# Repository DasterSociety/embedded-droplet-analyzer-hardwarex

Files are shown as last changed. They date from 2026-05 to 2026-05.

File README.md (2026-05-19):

# Modular On-Chip Droplet Sensor System

Open-source hardware companion to a manuscript submitted to _HardwareX_.
The project describes a modular, on-chip sensor system for flow and
monodispersity analysis in droplet-based microfluidics.

> Zenodo DOI: _to be added once the first release is archived._
>
> Manuscript citation: _to be added after acceptance._

## Repository contents

| Folder | Contents | License |
| --- | --- | --- |
| [`design/hardware/`](design/hardware/) | PCB design files (Gerbers, drill files) for each sensor board.  | CERN-OHL-S v2 |
| [`design/mechanical/`](design/mechanical/) | 3D design exports (STEP, STL) for chip, housing, and sensor bodies. | CERN-OHL-S v2 |
| [`firmware/`](firmware/) | Microcontroller firmware and data-acquisition code. | CERN-OHL-S v2 |

## Licensing

All design files and firmware in this repository are licensed under the
[CERN Open Hardware Licence Version 2 — Strongly Reciprocal
(CERN-OHL-S v2)](LICENSE-hardware).

Each source file carries an SPDX identifier:

```
SPDX-License-Identifier: CERN-OHL-S-2.0
```

## How to cite

_Citation block to be added once the Zenodo DOI has been minted and the
HardwareX article has been assigned a DOI._

## Reproducing the hardware

Full build and operation instructions are in the companion *HardwareX* manuscript,
sections 5 (Build instructions) and 6 (Operation instructions). The Design files
summary (§3) and Bill of materials (§4) in the manuscript cross-reference the exact
files in this repository.

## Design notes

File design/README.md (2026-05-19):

# design

All design files for the hardware. Licensed under CERN-OHL-S v2.

| Folder | Contents |
| --- | --- |
| [`hardware/`](hardware/) | PCB design files (Gerbers, drill files) for each sensor board. |
| [`mechanical/`](mechanical/) | 3D design exports (STEP, STL) for chip, housing, and sensor bodies. |

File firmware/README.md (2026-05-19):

# Firmware

Microcontroller firmware and data-acquisition code that runs on the
sensor hardware. Include build instructions (toolchain, flashing steps)
in this folder once populated. Licensed under CERN-OHL-S v2.

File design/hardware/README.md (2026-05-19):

# hardware

PCB design files for the sensor electronics. Licensed under CERN-OHL-S v2.

Each subdirectory corresponds to one board and contains:

- `GerberFiles/` — Gerber layers (copper, silkscreen, soldermask, solderpaste, profile) and a `.gbrjob` job file.
- `DrillFiles/` — drill file (`.xln`).

## Boards

| Folder | Description |
| --- | --- |
| [`arduino_shield/`](arduino_shield/) | Arduino shield that interfaces the sensor boards with the microcontroller. |
| [`leds_board/`](leds_board/) | LED driver board for optical excitation. |
| [`velocity_sensor/`](velocity_sensor/) | PCB for the droplet velocity sensor. |

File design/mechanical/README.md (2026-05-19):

# mechanical

3D design exports for all physical parts of the system. Licensed under CERN-OHL-S v2.

Each subdirectory contains a `.step` (neutral CAD exchange) and a `.stl` (3D-printing / visualization) export for the corresponding part.

## Parts

| Folder | Description |
| --- | --- |
| [`arduino_shield/`](arduino_shield/) | Mechanical body / footprint model of the Arduino shield PCB. |
| [`bottom_enclosure/`](bottom_enclosure/) | Bottom half of the device enclosure. |
| [`leds_board/`](leds_board/) | Mechanical body / footprint model of the LED driver PCB. |
| [`microfluidic_device/`](microfluidic_device/) | Microfluidic chip body. |
| [`top_enclosure/`](top_enclosure/) | Top half of the device enclosure. |
| [`tsl2561_sensor/`](tsl2561_sensor/) | Housing / mounting bracket for the TSL2561 light-to-digital sensor. |
| [`velocity_sensor/`](velocity_sensor/) | Mechanical body / footprint model of the velocity sensor PCB. |

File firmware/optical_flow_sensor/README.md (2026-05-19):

# Optical Flow Sensor — Firmware

Open-source unified firmware for an Arduino Zero–based optical flow sensor that combines two functions in a single image:

1. **Capture mode** — phased-burst TSL2561 light-intensity logger; writes `LOG_NNN.CSV` files to a microSD card with deterministic 17 ms sample spacing.
2. **Analysis mode** — on-device droplet characterization; walks every `LOG_*.CSV` on the card, runs the detrend / zero-crossing / pairing pipeline, and reports a cumulative droplet-length summary (count, mean, std, CV%) over Serial.

Companion firmware to the *HardwareX* manuscript "[manuscript title TBD]". For day-to-day operation, see [`OPERATION.md`](./OPERATION.md).

## Status

Active development. Target hardware: **Arduino Zero** (Atmel SAMD21G18A, Cortex-M0+, 32 KB SRAM, 256 KB Flash).

This firmware supersedes the standalone [`TSL2561_logger`](../TSL2561_logger/) and [`droplet_characterization`](../droplet_characterization/) projects, which remain in the repository as reference implementations of the individual modes.

## Quick start

Requires [PlatformIO](https://platformio.org/).

```sh
cd firmware/optical_flow_sensor
pio run                # build
pio run -t upload      # build + flash to Arduino Zero
pio device monitor     # open Serial debug at 115200 baud
```

PlatformIO automatically pulls all library dependencies declared in `platformio.ini`.

## Modes at a glance

From STANDBY (green LED steady):

| Press | Mode | Outcome |
|---|---|---|
| **B1** | Capture | Records up to ~51 s into RAM, then offloads to `LOG_NNN.CSV`. Repeat as needed via the PROMPT loop; B2 ends the session and returns to STANDBY. |
| **B3** | Analysis | Walks every `LOG_*.CSV` in numerical order, prints one progress line per file, then a cumulative summary. Returns to STANDBY automatically. |

The TSL2561 sensor and the SD card are **both required at boot** — the firmware refuses to enter STANDBY otherwise (steady red = sensor missing; red fast-blink = SD missing).

## Architecture

**Single shared 24 KB buffer.** Capture and Analysis are mutually exclusive in time, so their two data layouts overlay the same physical SRAM via a `union` (`SharedBuffer::g_buf`):

- *Capture view* — `Sample[3000]` (uint32_t millis + float lux), 24 KB.
- *Analysis view* — parallel `uint16_t t[3000]` + `float L[3000]`, 18 KB.

This keeps RAM peak at ~25 KB (24 KB buffer + ~1.2 KB analysis index arrays + library state), well inside the SAMD21's 32 KB ceiling.

**Phased-burst capture.** Each Capture burst fills the RAM buffer with no SD activity, then offloads it to the next free `LOG_NNN.CSV`. Because the sensor and SD card never run concurrently, the timestamps within each file are uniform 17 000 µs apart with sub-millisecond jitter — any visible deviation is real sensor behaviour, not storage jitter.

**Single-shot per file analysis.** Each `LOG_NNN.CSV` is read end-to-end into the shared buffer, then processed in a single pass. Per-droplet lengths from each file are folded into a running Welford accumulator that lives across files, so the final cumulative summary is mathematically identical to merging every droplet length into one one-pass calculation. Welford's algorithm extends naturally across batches.

Pipeline (one call per file, plus a single summary at the end):

```
readCSV()        →  uint16_t t[]   (zeroed ms)  +  float L[]   (raw lux)
detrend()        →  L[] -= mean(L)              (in-place)
findCrossings()  →  all / falling / rising index arrays
findExtrema()    →  dominant peak/trough between consecutive crossings
checkSampling()  →  reports if any peak-to-trough gap is < 2 samples
pickCloserEdge() →  snap each crossing to the nearer-zero bracketing sample
pairDroplets()   →  match falling↔rising edges, drop incomplete leading/trailing
statsAdd()       →  fold this file's droplet lengths into the running Stats
                                       ┄
statsSummarize() →  final mean / std / CV%      (called once at end of pass)
```

## File layout

```
src/
├── Config.h              ← pin map, timing, buffer dimensions, Ud, LED-state table
├── Leds.{h,cpp}          ← LED helpers (allOff, green, red, yellow, blue)
├── Buttons.{h,cpp}       ← debounced active-low Button class
├── SensorTSL.{h,cpp}     ← TSL2561 wrapper (1× gain, 13 ms integration)
├── Sampler.{h,cpp}       ← fixed-grid scheduler, fills SharedBuffer in capture
├── Logger.{h,cpp}        ← SD lifecycle, OFS-compatible row writer
├── FileIterator.{h,cpp}  ← walks LOG_001.CSV … LOG_999.CSV on the SD card
├── DropletAnalysis.{h,cpp} ← detrend / crossings / pairing / Welford stats
├── SharedBuffer.{h,cpp}  ← 24 KB union shared between capture and analysis
└── main.cpp              ← unified state machine + setup() / loop()
```

## Output format

### Capture mode

Each `LOG_NNN.CSV` is a stream of rows with **no header**:

```
<millis_as_float_2dp>, <lux_2dp>\r\n
```

Example:

```
12345.00, 234.56
12362.00, 234.78
12379.00, 234.55
```

The format matches the *OFS* detection pipeline's expected input (`OFS/Software Dev/OFS/lib/MyLib/Library.cpp:TSLReading_a`), so existing analysis code can read these files unchanged. Timestamps are milliseconds since power-on, captured immediately before the TSL2561 read.

### Analysis mode

Serial output at 115 200 baud. One compact line per file as it is processed:

```
LOG_001.CSV : 17 droplets (3000 samples)
LOG_002.CSV : 16 droplets (3000 samples, 1 undersampled)
```

Then a single cumulative block:

```
=== Cumulative results ===
Files processed: 2
Total droplets : 33
Avg length     : 612.34 um
Std dev        : 11.20 um
CV             : 1.83 %
```

Files that fail to read are reported as `LOG_NNN.CSV : read failed` and counted under `Files failed:` in the cumulative block.

## Configuration

Compile-time knobs in `src/Config.h`:

| Constant | Default | Meaning |
|---|---|---|
| `UD_MM_PER_S` | 1.55089 | Droplet velocity along the optical sensing path; sets the µm scale of the reported lengths |
| `SAMPLE_PERIOD_US` | 17 000 | Inter-sample interval in capture (~58 Hz) |
| `BUFFER_SIZE_SAMPLES` | 3 000 | Per-burst capacity (24 KB → ~51 s) |
| `MAX_CROSSINGS` | 100 | Upper bound on rising+falling crossings per file |
| `DEBOUNCE_MS` | 50 | Button debounce window |
| `FLUSH_EVERY_N` | 100 | SD-flush cadence during offload (crash-resilience) |
| `OFFLOAD_BLINK_MS` | 100 | OFFLOADING yellow fast-blink half-period |
| `PROMPT_BLINK_MS` | 500 | PROMPT green slow-blink half-period |
| `ERROR_BLINK_MS` | 200 | ERROR_SD red fast-blink half-period |
| `REJECT_FLASH_MS` | 400 | Brief red flash for rejected button press (e.g. analysis with no LOG files) |
| `DEBUG_OFS` | 1 | Set to 0 to disable all Serial output |

`SAMPLE_PERIOD_US` cannot go below ~14 000 µs without changing the TSL2561 driver — the 13 ms integration window plus driver overhead is the hard floor. `BUFFER_SIZE_SAMPLES` can be raised toward ~4000 on a 32 KB SAMD21 before the stack and library state become tight.

Length is computed as `length_k = (t_rise - t_fall) [ms] × Ud [µm/ms = mm/s]`, so `Ud` is the only experiment-specific value that needs to be fixed before flashing.

## Dependencies

Declared in `platformio.ini`, pulled automatically:

- `arduino-libraries/SD ^1.2.4`
- `adafruit/Adafruit Unified Sensor ^1.1.13`
- `adafruit/Adafruit TSL2561 ^1.1.0`

## Hardware

A minimal build requires:

- Arduino Zero (or compatible SAMD21G18A board)
- Adafruit TSL2561 breakout (or equivalent) on I²C
- microSD card module on hardware SPI, chip-select on D4
- 4 LEDs (green, red, yellow, blue) with current-limiting resistors
- 3 push buttons (B1, B2, B3) wired to ground

Full bill of materials, schematic, and assembly are in the *HardwareX* manuscript.

## License

CERN Open Hardware Licence Version 2 — Strongly Reciprocal (CERN-OHL-S v2).
See [`LICENSE-hardware`](../../LICENSE-hardware) at the repository root.

## Citation

If you use this firmware, please cite:

> [manuscript citation TBD]

## Maintainer

[Author / maintainer block TBD — e.g., name, affiliation, contact.]

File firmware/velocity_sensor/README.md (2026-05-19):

# Velocity Sensor — Firmware

Arduino Zero firmware for the dual-comparator optical droplet velocity sensor.
Companion firmware to the *HardwareX* manuscript.

## What this firmware does

Measures droplet velocity in a microfluidic channel by timing the transit between
two optical comparator sensors (COMP_A and COMP_B) separated by a known distance.
A SCADE-generated state machine processes the interrupt events and outputs velocity
in mm/s over Serial at 38 400 baud.

## Hardware requirements

- Arduino Zero (Atmel SAMD21G18A, Cortex-M0+)
- Two optical comparator outputs connected to D7 (COMP_A) and D6 (COMP_B)
- Two digital potentiometers (I²C address `0x2F`) for threshold adjustment:
  - DigiPot 1 on the default I²C bus (SDA/SCL)
  - DigiPot 2 on a second I²C bus (SDA = D11, SCL = D13)
- Status LEDs: green (D8), red (D9), yellow (D12), blue (A5), velocity LED (D10), OFS LED (A4)
- Buttons: B1 (D2), B2 (D3), B3 (D5) — active-low with internal pull-ups

Full bill of materials, schematic, and assembly are in the *HardwareX* manuscript.

## Quick start

Requires [PlatformIO](https://platformio.org/).

```sh
cd firmware/velocity_sensor
pio run                # build
pio run -t upload      # build + flash to Arduino Zero
pio device monitor     # open Serial at 38400 baud
```

## Configuration

Compile-time constants in `src/main.cpp`:

| Constant | Default | Meaning |
|---|---|---|
| `WIPER1` | 76 | DigiPot 1 wiper — sets COMP_B (Sensor 2) threshold |
| `WIPER2` | 83 | DigiPot 2 wiper — sets COMP_A (Sensor 1) threshold |
| `n` | 2 | Number of sensors active in the SCADE state machine |
| `DEBOUNCE_TIME_US` | 1000 | ISR debounce window (µs) |
| `MIN_INTER_S1_US` | 3000 | Minimum inter-event gap for Sensor 1 (µs) |
| `MIN_INTER_S2_US` | 3000 | Minimum inter-event gap for Sensor 2 (µs) |

The wiper values control the comparator thresholds and must be tuned to the signal
amplitude from your specific optical sensor assembly.

## Serial output

At 38 400 baud, the firmware prints one velocity value per detected droplet:

```
>>> Optical Droplet Velocity Sensor [OFS 3.0] <<<
Digital Potentiometer 1: 76
Digital Potentiometer 2: 83
n: 2
=== Velocity Measurements with ISR Debug ===
...
12.34
13.01
12.89
```

Each floating-point number is a droplet velocity in mm/s. Only values that differ
from the previous measurement and are > 0 are printed.

## Dependencies

Declared in `platformio.ini`; no external libraries are required beyond the
Arduino framework (pulled automatically by PlatformIO).

The SCADE/KCG state-machine code in `lib/KCG/` is a local library bundled with
the project and generated from the model file `VelSensor.cgcs`.

## License

CERN Open Hardware Licence Version 2 — Strongly Reciprocal (CERN-OHL-S v2).
See [`LICENSE-hardware`](../../LICENSE-hardware) at the repository root.

## Citation

If you use this firmware, please cite:

> [manuscript citation TBD — to be added after HardwareX acceptance]

## Maintainer

[Author block TBD — to be added before publication]

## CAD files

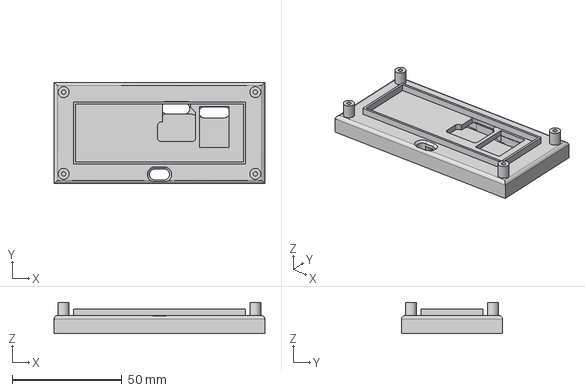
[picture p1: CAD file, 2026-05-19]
design/mechanical/bottom_enclosure/bottom_enclosure.step
96.0 x 46.0 x 14.3 mm

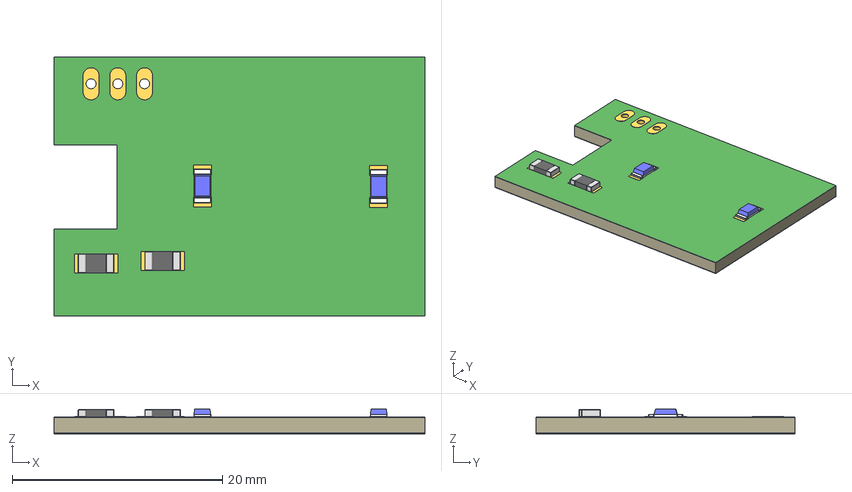
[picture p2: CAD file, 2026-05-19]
design/mechanical/leds_board/leds_board.step
35.3 x 24.6 x 2.37 mm
Board
1-copper
16-copper
1-soldermask
16-soldermask
RESC3216X70 x 2

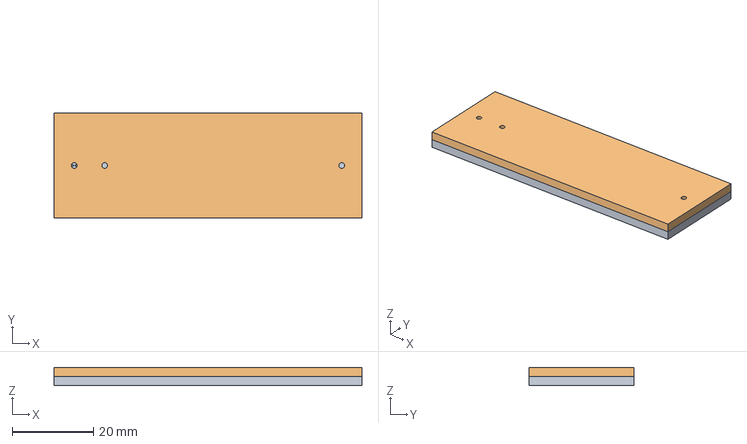
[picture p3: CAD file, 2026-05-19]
design/mechanical/microfluidic_device/microfluidic_device.step
76.0 x 26.0 x 4.46 mm

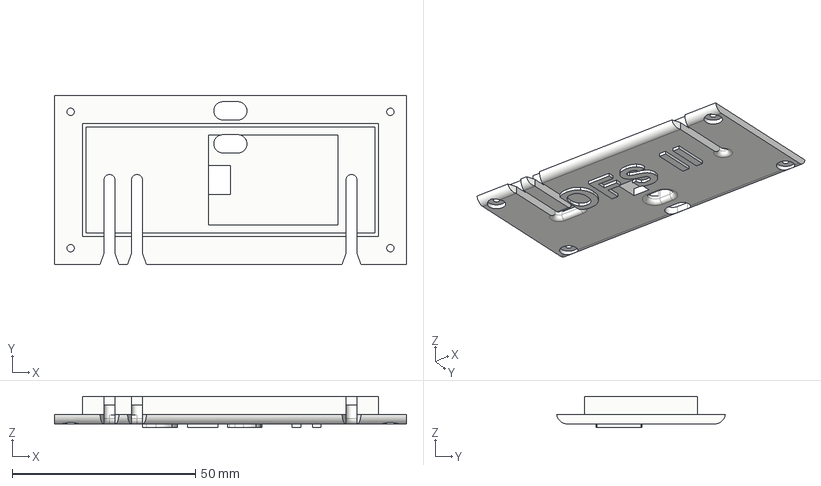
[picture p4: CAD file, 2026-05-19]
design/mechanical/top_enclosure/top_enclosure.step
96.0 x 46.0 x 8.50 mm

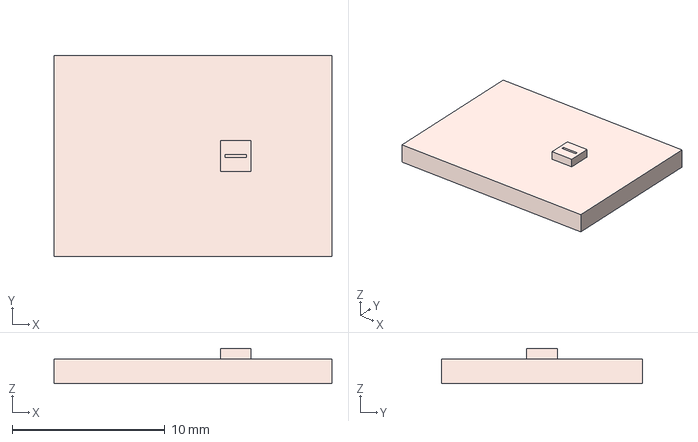
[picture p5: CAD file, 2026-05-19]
design/mechanical/tsl2561_sensor/tsl2561_sensor.step
18.2 x 13.2 x 2.30 mm

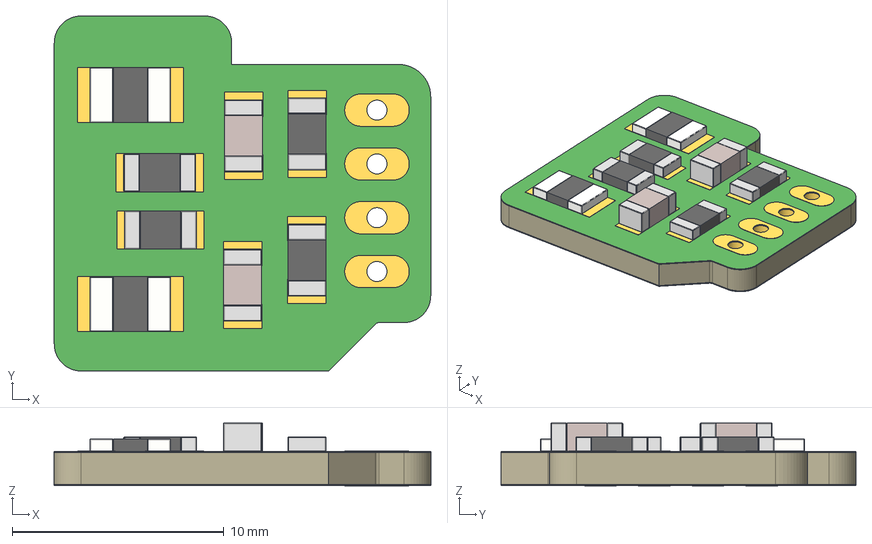
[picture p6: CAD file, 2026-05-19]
design/mechanical/velocity_sensor/velocity_sensor.step
17.8 x 16.8 x 2.97 mm
Board
1-copper
16-copper
1-soldermask
16-soldermask
12912179.f3d x 4
CAPC3216X135 x 2

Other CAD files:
design/mechanical/bottom_enclosure/bottom_enclosure.stl
design/mechanical/leds_board/leds_board.stl
design/mechanical/microfluidic_device/microfluidic_device.stl
design/mechanical/top_enclosure/top_enclosure.stl
design/mechanical/tsl2561_sensor/tsl2561_sensor.stl
design/mechanical/velocity_sensor/velocity_sensor.stl

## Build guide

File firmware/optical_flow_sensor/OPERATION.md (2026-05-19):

# Operation Manual

This manual covers day-to-day use of the optical flow sensor in both modes: capturing recordings and analysing them on-device. For build instructions and architectural details, see [`README.md`](./README.md). For the bill of materials and assembly, see the *HardwareX* manuscript.

## What this device does

A single press from STANDBY chooses one of two modes:

- **Capture mode (B1)** — samples ambient light intensity from the TSL2561 at ~58 Hz and stores each recording session as a self-contained CSV file on the microSD card. A single burst captures up to ~51 s of data into RAM with deterministic timing, then writes it out to the next available `LOG_NNN.CSV` file. Multiple bursts can be captured back-to-back.
- **Analysis mode (B3)** — walks every existing `LOG_*.CSV` on the card in numerical order, runs the droplet characterization pipeline on each file, and prints a cumulative summary (file count, droplet count, mean length, standard deviation, CV%) over Serial. Returns to STANDBY automatically when done.

## Hardware overview

Pin assignments are fixed in firmware (`src/Config.h`) and must match how your board is wired:

| Function | Pin | Notes |
|---|---|---|
| Capture button (B1) | D2 | Active-low, INPUT_PULLUP |
| End-session button (B2) | D3 | Active-low, INPUT_PULLUP |
| Analysis button (B3) | D5 | Active-low, INPUT_PULLUP |
| Green LED | D8 | Standby / capturing |
| Red LED | D9 | Error / rejected press |
| Yellow LED | D12 | Init / offloading / prompt / processing |
| Blue LED | A5 | Capturing / processing |
| SD chip-select | D4 | |
| TSL2561 SDA / SCL | board defaults | I²C |
| SD MOSI / MISO / SCK | board defaults | hardware SPI (fixed on Zero) |

## Preparing the SD card

1. Format the card as **FAT32**.
   - macOS: Disk Utility → Erase → MS-DOS (FAT).
   - Windows: SD Memory Card Formatter (recommended for cards larger than 32 GB).
2. Confirm the card mounts cleanly. Existing `LOG_NNN.CSV` files from previous sessions are fine — the firmware skips occupied filenames during Capture and walks every existing one during Analysis.
3. Insert the card into the SD module **before powering the device**.

The firmware refuses to leave INIT (red fast-blink) if no card is detected.

## LED reference

| LED state | Meaning |
|---|---|
| Yellow steady | Initialising — testing TSL2561 and SD card |
| Green steady | **Standby** — ready (B1 = Capture, B3 = Analysis) |
| Green steady + Blue steady | **Capturing** — RAM buffer filling, do not remove power |
| Yellow fast-blink (~10 Hz) | **Offloading** — writing buffer to SD, do not remove power or card |
| Yellow steady + Green slow-blink (~1 Hz) | **Prompt** — choose: B1 for next file, B2 to end session |
| Yellow steady + Blue steady | **Processing** — analysing LOG files |
| Brief red flash (~400 ms) | Pressed button valid for some mode but unavailable now (e.g. B3 with no LOG files on card) |
| Red steady | TSL2561 not detected at boot |
| Red fast-blink (~5 Hz) | SD card error |

## Button reference

| Button | Active state | Action |
|---|---|---|
| B1 | Standby | Enter Capture mode (start a recording burst) |
| B1 | Capturing | Stop the current burst early and offload |
| B1 | Prompt | Start the next burst (new file) |
| B2 | Prompt | End the session and return to Standby |
| B3 | Standby | Enter Analysis mode (process every `LOG_*.CSV`) |

Button presses outside the active states listed above are ignored.

## Recording an experiment — step by step

### 1. Power on

Connect the device via USB or its dedicated power input. Watch the LEDs:

- The yellow LED comes on briefly (initialisation, < 1 s).
- The green LED comes on steadily — you are now in **Standby**.

If a red LED comes on instead, see *Troubleshooting* below before proceeding.

### 2. Start a recording

Press **B1**. The blue LED comes on (the green LED stays on). The device is now capturing data into RAM at ~58 Hz. Avoid pressing other buttons during capture unless you want to stop early.

### 3. Wait, or stop early

Capture continues until either of:

- You press **B1** again (manual stop), or
- The 51-second buffer fills (automatic stop).

In either case, capture ends and offload begins automatically.

### 4. Wait for the offload

The blue and green LEDs go off; the yellow LED begins fast-blinking. The firmware is writing the captured data to the next free `LOG_NNN.CSV` file on the SD card. **Do not remove power or the SD card during this phase.** Offload typically takes 1–3 s on a healthy card.

### 5. Decide what to do next

When offload finishes you enter **Prompt**: yellow LED steady, green LED slow-blinking.

- **Press B1** to start another recording immediately. The next file is auto-numbered (e.g., `LOG_002.CSV` after `LOG_001.CSV`).
- **Press B2** to end the session. The device returns to Standby (green LED steady), at which point it is safe to remove the SD card or power-cycle.

### 6. Repeat as needed

A single session can capture as many files as the SD card has space for, up to file 999. There is no hard limit on the number of sessions per card other than the 999 file-slot ceiling.

## Running an analysis pass — step by step

### 1. From STANDBY, press B3

The green LED switches off; yellow + blue come on (Processing). The firmware walks every `LOG_*.CSV` on the card in numerical order, fold-merging the per-droplet lengths from each file into a single Welford accumulator.

If the card has no `LOG_*.CSV` files, the red LED briefly flashes (~400 ms) and the device stays in Standby — there is nothing to analyse.

### 2. Watch the Serial monitor

At 115 200 baud you'll see one compact line per file as it completes:

```
LOG_001.CSV : 17 droplets (3000 samples)
LOG_002.CSV : 16 droplets (3000 samples, 1 undersampled)
```

The `undersampled` annotation means at least one peak-to-trough transition was resolved by fewer than 2 samples in that file — flag for manual review but the droplet count is still computed.

### 3. Read the cumulative summary

After the last file, the firmware prints:

```
=== Cumulative results ===
Files processed: 2
Total droplets : 33
Avg length     : 612.34 um
Std dev        : 11.20 um
CV             : 1.83 %
```

The yellow + blue LEDs go off and the green LED returns to steady — back in **Standby**, ready for either mode again. The analysis pass does not modify the SD card.

### 4. Re-run if needed

Pressing **B3** again re-runs the same pass with a fresh Welford accumulator (the previous summary remains in the Serial scrollback). Useful after editing/replacing files on the card.

## State diagram

```
                 ┌─────┐
                 │INIT │ Y on
                 └──┬──┘
                    │ TSL2561 + SD OK
                    ▼
       ┌───────► STANDBY  ◄──────────────────────────┐
       │         G on                                │
       │       ┌──┴──┐                               │
       │      B1     B3                              │
       │       │      │                              │
       │       ▼      ▼                              │
       │   CAPTURING  PROCESSING                     │
       │   G + B on   Y + B on                       │
       │       │      │                              │
       │   B1 / full  walks LOG_*.CSV                │
       │       ▼      │ prints cumulative summary    │
       │   OFFLOADING └──────────────────────────────┘
       │   Y fast-blink
       │       │
       │       ▼
       │     PROMPT  Y on, G slow-blink
       │     ├── B1 → CAPTURING (next file)
       │     └── B2 → STANDBY
       └───────────
```

## Recovering data from the card

1. End the capture session: in Prompt state, press **B2** so the green LED goes steady.
2. Remove power.
3. Eject the microSD card and read it on a computer.
4. Copy the `LOG_NNN.CSV` files to your analysis directory.

Each file is plain CSV, no header, format `<millis_as_float>, <lux>` per row:

```
12345.00, 234.56
12362.00, 234.78
12379.00, 234.55
```

Timestamps are milliseconds since the Arduino was powered on (boot-relative). Within a single file, samples are uniformly spaced 17 ms apart with sub-millisecond jitter; the act of writing to SD did **not** influence the spacing because no SD activity occurred during capture.

## Specifications

| Parameter | Value |
|---|---|
| Sample rate | ~58 Hz (one sample every 17 ms) |
| TSL2561 gain | 1× |
| TSL2561 integration time | 13 ms (fastest setting) |
| Maximum file duration | ~51 s (3000 samples × 17 ms) |
| Maximum files per card | 999 (`LOG_001` … `LOG_999`) |
| File format | CSV, no header, OFS-compatible |
| Timestamp resolution | 1 ms (since power-on) |
| Timestamp format | float, 2 decimal places |
| Lux format | float, 2 decimal places |
| Per-burst SRAM use | 24 KB (shared with analysis buffer) |
| Analysis pass time | < 1 s per LOG file on a healthy card |

## Troubleshooting

**Red LED steady at boot.**
The TSL2561 is not responding on I²C. Check SDA/SCL wiring, sensor power, and confirm the address strap (default `TSL2561_ADDR_FLOAT`) matches your breakout board. Power-cycle to retry.

**Red LED fast-blink at boot.**
SD card not detected or unreadable. Confirm the card is inserted, formatted as FAT32, and that chip-select (D4) is wired correctly. Power-cycle to retry.

**Red LED fast-blink during operation.**
Could not open a new `LOG_NNN.CSV` file during offload. Either all 999 slots are taken, or the card is full. Move some old files off the card (or use a fresh card) and power-cycle.

**Brief red flash when pressing B3.**
There are no `LOG_*.CSV` files on the card to analyse. Run a Capture pass first, or insert a card that already has logs.

**Offload phase takes much longer than expected.**
Consumer SD cards occasionally pause for several seconds to perform internal garbage collection. The yellow LED continues fast-blinking throughout — this is normal. If a card consistently exceeds 10 s for a 24 KB write, replace it with a known-good card.

**File appears truncated after a power loss.**
Mid-offload power loss leaves a partial file containing every row written before the last `flush()` (every 100 rows by default). The remainder of the buffer is lost. To minimise risk, ensure the device is powered until the yellow LED returns to steady before disconnecting.

**Analysis prints `LOG_NNN.CSV : read failed`.**
The file could not be opened (corrupt entry, encrypted card, or transient SD glitch). The pass continues with subsequent files; the failed file is counted under `Files failed:` in the cumulative summary.

**Some files report `undersampled`.**
At least one peak-to-trough transition in that file was resolved by fewer than 2 samples — typically a sign that flow rate or droplet frequency was high relative to the 58 Hz sample rate. The droplet count is still computed but the per-file length estimates may be biased; treat the affected file as a soft warning.

**The Serial monitor shows nothing.**
Confirm the monitor is at 115 200 baud. Note that `DEBUG_OFS` is enabled by default; set it to `0` in `src/Config.h` for a silent release build.

**Buffer fills sooner than ~51 s in Capture.**
Confirm `BUFFER_SIZE_SAMPLES` and `SAMPLE_PERIOD_US` in `src/Config.h` have not been altered. At defaults (3000 samples × 17 000 µs), the burst lasts 51.0 s.

## Recompiling the firmware

See [`README.md`](./README.md) for the build process. The compile-time constants in `src/Config.h` can be tuned without touching any other file:

- Edit **`UD_MM_PER_S`** to match your experiment's droplet velocity (mm/s). This is the only value that has to change between experiments; lengths reported in Analysis mode scale linearly with it.
- Increase **`BUFFER_SIZE_SAMPLES`** to extend per-file duration. Up to ~4000 is safe on the 32 KB SAMD21; beyond that the stack and library state become tight.
- Decrease **`SAMPLE_PERIOD_US`** to push the sample rate. Below ~14 000 µs the TSL2561 driver cannot keep up — the 13 ms integration window is a hard floor.
- Set **`DEBUG_OFS = 0`** for a release build with no Serial output.

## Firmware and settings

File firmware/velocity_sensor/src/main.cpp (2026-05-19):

#include <Arduino.h>
#include <Wire.h>
#include "wiring_private.h"
#include "velSensor.h"
#include "velSensor.c"
// Clean version Win

// NOTE: Second I2C port: SDA 11; SCL 13;
//  Seting second I2C port to use pins 11 and 13
#define digiPot 0x2F // I2C address of the digital potentiometers
TwoWire myWire(&sercom1, 11, 13);

// NOTE: I/O pins of new Arduino Shield:
const uint8_t LED_R = 9;
const uint8_t LED_G = 8;
const uint8_t LED_Y = 12;
const uint8_t LED_B = A5;
const uint8_t LED_VEL = 10; // Light source for Vel Sensor
const uint8_t LED_OFS = A4; // Light source for OFS TSL2561
const uint8_t button1 = 2;  // Button 1
const uint8_t button2 = 3;  // Button 2
const uint8_t button3 = 5;  // Button 3

// NOTE: Velocity Sensor Comparator output pins:

const uint8_t comp_s1 = 7; // COMP_A
const uint8_t comp_s2 = 6; // COMP_B

// Globals
volatile unsigned long lastTriggerTime_s1 = 0; // Last trigger time for Sensor 1
volatile unsigned long lastTriggerTime_s2 = 0; // Last trigger time for Sensor 2
volatile unsigned long lastValidS1Time = 0;    // Timestamp of last accepted ISR1
volatile unsigned long lastValidS2Time = 0;    // Timestamp of last accepted ISR2

// Debounce timing constants
const unsigned long DEBOUNCE_TIME_US = 1000; // 1ms debounce for high-speed droplets
const unsigned long MIN_INTER_S1_US = 3000;   // Ignore S1 edges <3ms after previous valid S1
const unsigned long MIN_INTER_S2_US = 3000;   // Ignore S2 edges <3ms after previous valid S2

// NOTE: Digipots Wiper values:
// CONFIG: W1 -> DigiPot1 -> COMP_1 -> Sensor 2 (Second sensor contacted to the droplet)
// CONFIG: W2 -> DigiPot2 -> COMP_2 -> Sensor 1 (First sensor contacted to the droplet)
// CONFIG: n -> Number of droplets to reset timer 2.

const uint8_t WIPER1 = 76; // RED
const uint8_t WIPER2 = 83; // GREEN
const uint8_t n = 2;       // Number of sensors (1 or 2)

// NOTE: SCADE init variables
inC_velSensor inC;
outC_velSensor outC;
kcg_uint32 Time = 0;
kcg_bool fs1 = false;
kcg_bool fs2 = false;
float prevVel;

void isr_1()
{
  // Interrupt for COMP_A (Sensor 1 - First sensor contacted by droplet)
  unsigned long currentTime = micros();
  unsigned long elapsedTime = currentTime - lastTriggerTime_s1;

  // Improved debouncing and per-sensor inter-event guard
  if (elapsedTime > DEBOUNCE_TIME_US && (currentTime - lastValidS1Time) > MIN_INTER_S1_US && digitalRead(comp_s1) == HIGH)
  {
    lastTriggerTime_s1 = currentTime;
    lastValidS1Time = currentTime;
    fs1 = true;     // Set SCADE input flag

    // Lightweight ISR: capture timestamp and signal main loop to process SCADE
    Time = currentTime;     // Capture timestamp associated with this event
  }
}

void isr_2()
{
  // Interrupt for COMP_B (Sensor 2 - Second sensor contacted by droplet)
  unsigned long currentTime = micros();
  unsigned long elapsedTime = currentTime - lastTriggerTime_s2;

  // Improved debouncing and per-sensor inter-event guard
  if (elapsedTime > DEBOUNCE_TIME_US && (currentTime - lastValidS2Time) > MIN_INTER_S2_US && digitalRead(comp_s2) == HIGH)
  {
    lastTriggerTime_s2 = currentTime;
    lastValidS2Time = currentTime;
    fs2 = true;     // Set SCADE input flag

    // Lightweight ISR: capture timestamp and signal main loop to process SCADE
    Time = currentTime;     // Capture timestamp associated with this event
  }
}

void setWiper(TwoWire &bus, uint8_t value)
{
  // Set the wiper value for the digital potentiometer
  bus.beginTransmission(digiPot);
  bus.write(value); // Set the wiper value
  bus.endTransmission();
}

void setupPins()
{
  // Set pin modes for all I/O pins
  pinMode(comp_s1, INPUT);        // Comparator output for Sensor 1
  pinMode(comp_s2, INPUT);        // Comparator output for Sensor 2
  pinMode(LED_VEL, OUTPUT);       // Velocity sensor LED
  pinMode(LED_B, OUTPUT);         // Blue LED indicator
  pinMode(LED_Y, OUTPUT);         // Yellow LED indicator
  pinMode(LED_R, OUTPUT);         // Red LED indicator
  pinMode(LED_G, OUTPUT);         // Green LED indicator
  pinMode(LED_OFS, OUTPUT);       // OFS TSL2561 LED
  pinMode(button1, INPUT_PULLUP); // Button 1 with pullup
  pinMode(button2, INPUT_PULLUP); // Button 2 with pullup
  pinMode(button3, INPUT_PULLUP); // Button 3 with pullup

  // Initialize LED states
  digitalWrite(LED_VEL, HIGH); // Turn on velocity sensor LED
  digitalWrite(LED_B, LOW);    // Turn off other LEDs initially
  digitalWrite(LED_Y, LOW);
  digitalWrite(LED_R, LOW);
  digitalWrite(LED_G, LOW);
  digitalWrite(LED_OFS, LOW);
}

void setup()
{
  // SCADE function initialization
  velSensor_init(&outC); // Initialize SCADE function
  // Initialize I2C
  Wire.begin();                  // Initialize I2C
  myWire.begin();                // Initialize second I2C port
  pinPeripheral(11, PIO_SERCOM); // Set pin 11 to SERCOM mode
  pinPeripheral(13, PIO_SERCOM); // Set pin 13 to SERCOM mode

  // Initialize serial communication
  Serial.begin(38400);
  Serial.println(">>> Optical Droplet Velocity Sensor [OFS 3.0] <<<");
  delay(10);

  // Set digiPot wiper values
  setWiper(Wire, WIPER1);   // Set wiper value for DigiPot1
  setWiper(myWire, WIPER2); // Set wiper value for DigiPot2
  myWire.end();
  Wire.end();

  // Set up all pin modes and initial states
  setupPins();

  // Set up interrupts
  attachInterrupt(digitalPinToInterrupt(comp_s1), isr_1, RISING); // Attach interrupt for COMP_A
  attachInterrupt(digitalPinToInterrupt(comp_s2), isr_2, RISING); // Attach interrupt for COMP_B

  inC.n = n; // Set input count for Sensor 2

  // Print initial message
  Serial.print("Digital Potentiometer 1: ");
  Serial.println(WIPER1);
  Serial.print("Digital Potentiometer 2: ");
  Serial.println(WIPER2);
  Serial.print("n: ");
  Serial.println(inC.n);
  Serial.println("=== Velocity Measurements with ISR Debug ===");
  Serial.println("Format: Vel: [velocity] mm/s, ISR1 calls: [count], ISR2 calls: [count], n: [counter], startTime: [us], stopTime: [us], timeDiff: [us]");
  Serial.println("DEBUG format: TimerInit, TimerStop, Counter_s2, ISR1 total, ISR2 total, fs1, fs2");
  Serial.println("ISR Debug: ISR1/ISR2 with count, Time, timer states, and timing values");
  delay(1000);
}

void loop()
{
  // Update LED indicators based on SCADE outputs
  digitalWrite(LED_B, outC.timerInit);
  digitalWrite(LED_Y, outC.timerStop);

  // Process SCADE in main loop when flags are set (no debug prints)
  if (fs1 || fs2)
  {
    velSensor(&inC, &outC);
  }

  // Print velocity only if it changed and is valid
  if (outC.vel != prevVel && outC.vel > 0.0)
  {
    Serial.println(outC.vel);
    prevVel = outC.vel;
  }

  // No periodic debug to keep serial line quiet

  // Reset sensor flags in main loop (safer than in ISR)
  // This prevents potential race conditions
  if (fs1 == true)
  {
    fs1 = false;     // Reset SCADE flag for Sensor 1
  }
  if (fs2 == true)
  {
    fs2 = false;     // Reset SCADE flag for Sensor 2
  }
}

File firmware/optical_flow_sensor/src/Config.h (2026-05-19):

#pragma once

#include <Arduino.h>

#ifndef DEBUG_OFS
#define DEBUG_OFS 1
#endif

namespace Config {

// ── Timing ────────────────────────────────────────────────────────────────────
constexpr unsigned long DEBOUNCE_MS         = 50;
constexpr unsigned long SAMPLE_PERIOD_US    = 17000;   // ~58 Hz: 13 ms TSL2561 integration + overhead
constexpr unsigned long ERROR_BLINK_MS      = 200;     // SD error: red LED half-period
constexpr unsigned long OFFLOAD_BLINK_MS    = 100;     // OFFLOADING: yellow fast-blink half-period
constexpr unsigned long PROMPT_BLINK_MS     = 500;     // PROMPT: green slow-blink half-period
constexpr unsigned long REJECT_FLASH_MS     = 400;     // brief red flash for rejected button press
constexpr unsigned long SERIAL_WAIT_MS      = 3000;    // 0 = don't wait for USB serial
constexpr unsigned int  FLUSH_EVERY_N       = 100;     // crash-resilience during offload

// ── Buffer dimensions ─────────────────────────────────────────────────────────
// 3000 samples × 17 ms ≈ 51 s per LOG_NNN.CSV file.
// Capture view (Sampler::Sample[]):  3000 × 8 B = 24 KB
// Analysis view (uint16_t t[] + float L[]): 3000 × 6 B = 18 KB
// Both views overlay the same physical buffer (SharedBuffer::g_buf) — modes are
// mutually exclusive in time, so the union is safe.
constexpr size_t   BUFFER_SIZE_SAMPLES = 3000;
constexpr uint16_t MAX_CROSSINGS       = 100;

// ── Experiment parameter ──────────────────────────────────────────────────────
// Droplet velocity along the optical sensing path.
// length_k [µm] = (t_rise - t_fall) [ms] × Ud [µm/ms = mm/s]
// Edit and rebuild to match your experiment.
constexpr float UD_MM_PER_S = 1.55089f;

// ── Pins ──────────────────────────────────────────────────────────────────────
constexpr uint8_t PIN_B1    = 2;    // STANDBY: enter Capture; CAPTURING: stop early; PROMPT: next burst
constexpr uint8_t PIN_B2    = 3;    // PROMPT: end session → STANDBY
constexpr uint8_t PIN_B3    = 5;    // STANDBY: enter Analysis
constexpr uint8_t PIN_LED_G = 8;    // ready / capturing
constexpr uint8_t PIN_LED_R = 9;    // error / rejected press
constexpr uint8_t PIN_LED_Y = 12;   // init / offloading / prompt / processing
constexpr uint8_t PIN_LED_B = A5;   // capturing / processing
constexpr uint8_t PIN_SD_CS = 4;

// ── LED state table (informational; states drive these in main.cpp) ───────────
//   INIT        → Y on
//   STANDBY     → G on
//   CAPTURING   → G on  + B on
//   OFFLOADING  → Y fast-blink
//   PROMPT      → Y on  + G slow-blink
//   PROCESSING  → Y on  + B on
//   ERROR_TSL   → R steady
//   ERROR_SD    → R fast-blink

}  // namespace Config

#if DEBUG_OFS
  #define DBG(x)   Serial.print(x)
  #define DBGLN(x) Serial.println(x)
#else
  #define DBG(x)
  #define DBGLN(x)
#endif

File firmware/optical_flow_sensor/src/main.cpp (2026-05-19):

/*
 * Optical Flow Sensor — unified firmware (capture + analysis)
 * Board : Arduino Zero (SAMD21 Cortex-M0+)
 *
 * Two user-selectable modes from STANDBY:
 *   B1 → Capture mode    : phased-burst light intensity logger that writes
 *                          LOG_NNN.CSV files to the microSD card. Mirrors the
 *                          standalone TSL2561 logger flow.
 *   B3 → Analysis mode   : walks every LOG_*.CSV on the card, runs the droplet
 *                          characterization pipeline, prints per-file progress
 *                          and a cumulative summary, then returns to STANDBY.
 *
 * Capture and analysis are mutually exclusive in time, so the 24 KB sample
 * buffer is shared between them via SharedBuffer::g_buf.
 *
 * Pin map
 * -------
 *   D2   B1   STANDBY: enter Capture; CAPTURING: stop early; PROMPT: next burst
 *   D3   B2   PROMPT: end session → STANDBY
 *   D5   B3   STANDBY: enter Analysis
 *   D8   LED_G  ready / capturing / prompt slow-blink
 *   D9   LED_R  error / rejected press
 *   D12  LED_Y  init / offloading / prompt / processing
 *   A5   LED_B  capturing / processing
 *   D4   SD chip-select
 *   SDA/SCL    TSL2561 I2C
 *   MOSI=23, MISO=22, SCK=24  (hardware SPI, fixed on Zero)
 *
 * State machine
 * -------------
 *   INIT       (Y on)            — probe TSL2561 + SD; both required
 *   STANDBY    (G on)            — B1 → CAPTURING, B3 → PROCESSING
 *   CAPTURING  (G + B on)        — RAM buffer fills; B1 or buffer-full → OFFLOADING
 *   OFFLOADING (Y fast-blink)    — buffer is written to LOG_NNN.CSV; auto → PROMPT
 *   PROMPT     (Y on, G slow-blink)
 *                                — B1 → CAPTURING (next file); B2 → STANDBY
 *   PROCESSING (Y + B on)        — walk LOG_*.CSV, fold into Welford, print summary; auto → STANDBY
 *   ERROR_TSL  (R steady)        — TSL2561 not found at boot
 *   ERROR_SD   (R fast-blink)    — SD mount failed
 *
 * CSV format (per row)
 * --------------------
 *   "<millis_as_float_2dp>, <lux_2dp>\r\n"   — no header.
 *   Matches the OFS project's Serial output (Library.cpp:TSLReading_a) so the
 *   existing detection pipeline can read these files unchanged.
 *
 * Compile-time experiment parameter
 * ---------------------------------
 *   Config::UD_MM_PER_S — droplet velocity along the sensing path.
 *   Edit Config.h and rebuild to match your experiment.
 */

#include <Arduino.h>

#include "Config.h"
#include "Leds.h"
#include "Buttons.h"
#include "SensorTSL.h"
#include "Sampler.h"
#include "Logger.h"
#include "FileIterator.h"
#include "DropletAnalysis.h"
#include "SharedBuffer.h"

// ── Static SRAM (analysis-only working arrays, ~1.2 KB) ───────────────────────
static uint16_t g_allCrossings[Config::MAX_CROSSINGS];
static uint16_t g_fallingIdx[Config::MAX_CROSSINGS];
static uint16_t g_risingIdx[Config::MAX_CROSSINGS];
static uint16_t g_extremaIdx[Config::MAX_CROSSINGS];
static uint16_t g_fallingPts[Config::MAX_CROSSINGS];
static uint16_t g_risingPts[Config::MAX_CROSSINGS];

enum class State : uint8_t
{
    INIT,
    STANDBY,
    CAPTURING,
    OFFLOADING,
    PROMPT,
    PROCESSING,
    ERROR_TSL,
    ERROR_SD,
};
static State g_state = State::INIT;

static Button g_b1(Config::PIN_B1);
static Button g_b2(Config::PIN_B2);
static Button g_b3(Config::PIN_B3);

static unsigned long g_lastBlinkMs = 0;
static bool g_blinkOn = false;
static char g_filename[13]; // "LOG_NNN.CSV" + NUL

// ── Cumulative state for an analysis pass ─────────────────────────────────────
static DropletAnalysis::Stats g_stats;
static uint16_t g_filesProcessed = 0;
static uint16_t g_filesFailed = 0;

// ── Helpers ───────────────────────────────────────────────────────────────────

static void enterStandby()
{
    Leds::allOff();
    Leds::green(true);
    g_state = State::STANDBY;
    DBGLN(F("STANDBY — B1: Capture, B3: Analysis"));
}

// Brief red flash when the user presses a button that's valid for some mode
// but unavailable right now (e.g. B3 pressed but no LOG_*.CSV on card).
static void rejectFlash()
{
    Leds::green(false);
    Leds::red(true);
    delay(Config::REJECT_FLASH_MS);
    Leds::red(false);
    Leds::green(true);
}

// ── Analysis pipeline (one call per file) ─────────────────────────────────────

static void processFile(const char *filename)
{
    DBG(F("PROCESSING → "));
    DBGLN(filename);

    uint16_t n = DropletAnalysis::readCSV(filename,
                                          SharedBuffer::g_buf.anal.t,
                                          SharedBuffer::g_buf.anal.L,
                                          (uint16_t)Config::BUFFER_SIZE_SAMPLES);
    if (n == 0u)
    {
        Serial.print(filename);
        Serial.println(F(" : read failed"));
        g_filesFailed++;
        return;
    }

    DropletAnalysis::detrend(SharedBuffer::g_buf.anal.L, n);

    uint16_t nFalling = 0, nRising = 0;
    uint16_t nAll = DropletAnalysis::findCrossings(
        SharedBuffer::g_buf.anal.L, n, g_allCrossings,
        g_fallingIdx, &nFalling,
        g_risingIdx, &nRising,
        Config::MAX_CROSSINGS);

    if (nAll > 1u)
    {
        DropletAnalysis::findExtrema(SharedBuffer::g_buf.anal.L,
                                     g_allCrossings, nAll, g_extremaIdx);
    }

    uint16_t worstGap = 0, nBad = 0;
    bool samplingOK = false;
    uint16_t nExtrema = (nAll > 1u) ? (uint16_t)(nAll - 1u) : 0u;
    if (nExtrema > 0u)
    {
        samplingOK = DropletAnalysis::checkSampling(g_extremaIdx, nExtrema,
                                                    &worstGap, &nBad);
    }

    DropletAnalysis::pickCloserEdge(SharedBuffer::g_buf.anal.L,
                                    g_fallingIdx, nFalling, g_fallingPts);
    DropletAnalysis::pickCloserEdge(SharedBuffer::g_buf.anal.L,
                                    g_risingIdx, nRising, g_risingPts);

    uint16_t fallStart = 0, riseStart = 0;
    uint16_t nDroplets = DropletAnalysis::pairDroplets(
        g_fallingIdx, nFalling, g_risingIdx, nRising,
        &fallStart, &riseStart);

    if (nDroplets > 0u)
    {
        DropletAnalysis::statsAdd(&g_stats,
                                  SharedBuffer::g_buf.anal.t,
                                  g_fallingPts, g_risingPts,
                                  nDroplets, fallStart, riseStart,
                                  Config::UD_MM_PER_S);
    }
    g_filesProcessed++;

    Serial.print(filename);
    Serial.print(F(" : "));
    Serial.print(nDroplets);
    Serial.print(F(" droplets ("));
    Serial.print(n);
    Serial.print(F(" samples"));
    if (!samplingOK && nExtrema > 0u)
    {
        Serial.print(F(", "));
        Serial.print(nBad);
        Serial.print(F(" undersampled"));
    }
    Serial.println(F(")"));
}
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
